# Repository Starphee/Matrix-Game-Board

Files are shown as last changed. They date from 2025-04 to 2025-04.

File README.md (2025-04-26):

# Matrix Game Board

*Interactive Multi-Matrix Tic Tac Toe Board*

---

## Project Overview

The **Matrix Game Board** is an original engineering project by Dorian Todd, designing and building an **interactive Tic Tac Toe** game using multiple **LED matrix displays** as both the **visual board** and the **input mechanism**.

Developed as a technical challenge, this project documents the entire process, from initial research and CAD design through manufacturing, complex wiring, assembly, testing, and iteration. It highlights the innovative approach of using the LED matrices themselves as pressure-sensitive buttons via underlying mechanical switches, all within a compact and portable form factor.

This repository contains the technical documentation, design files, firmware, and other resources related to the project.

> [!NOTE]
> This documentation serves to demonstrate the project's creation process and does not intend to be a step-by-step instruction manual for replication. 



## Key Features

*   **Interactive LED Display:** Utilizes nine 8x8 LED matrix modules (HT16K33) to display the Tic Tac Toe game state.
*   **Integrated Input:** Each matrix display doubles as a pressure-sensitive button via a low-profile mechanical keyboard switch mounted underneath.
*   **Tactile Feedback:** Mechanical switches provide satisfying tactile response for gameplay interaction.
*   **Compact Design:** Designed to fit within a 6.5-inch cubed area, adhering to competition constraints.
*   **Custom Enclosure:** Features a 3D-printed base with integrated component mounts and a laser-cut top panel.
*   **Advanced Electronics:** Incorporates an Adafruit Feather ESP32 V2 microcontroller, I2C multiplexing for displays, and analog multiplexing for switch inputs to manage numerous components efficiently.
*   **Audio Feedback:** Includes a Piezo Buzzer with volume control for game sounds.
*   **Battery Powered:** Designed with support for a Lithium Polymer battery for portability.
*   **Iterative Design Process:** Documentation showcases the challenges faced during prototyping, wiring, and assembly, and the design improvements made to overcome them.

## Technical Details

The project is built upon the following core components:

*   **Microcontroller:** Adafruit ESP32 Feather V2
*   **Display:** 9x Ada8x8 LED Matrix Modules (HT16K33)
*   **Display Multiplexer:** TCA9548A I2C Multiplexer (Manages the I2C addresses of the nine matrix displays)
*   **Input Switches:** 9x Kailh Low-Profile Mechanical Keyboard Switches
*   **Input Multiplexer:** CD74HC4067 16-Channel Analog Multiplexer (Condenses the 9 switch inputs down to 4 microcontroller pins)
*   **Audio:** 1x Piezo Buzzer, 1x Volume Potentiometer
*   **Power:** 1x Power Switch, 1x Power LED, 1x Lithium Polymer 1000mAh 3.7v battery (charging via ESP32's USB-C port)
*   **Casing:** 3D-printed PLA base, Laser-cut wood top panel / side panels

A complete Bill of Materials (BoM) can be found [here](#bill-of-materials) or in the technical documentation file.

## Project Files

This repository includes (or will include) the following files:

*   `Technical Documentation.pdf`: The source document detailing the project process.
*   `/CAD/`: Fusion360 files and exported formats (STL, STEP) for the 3D-printed base and laser-cut panels.
*   `/Laser_Cut_Files/`: Files (DXF or similar) used for laser cutting the panel parts.
*   `/Firmware/`: Arduino code for the ESP32 Feather, including game logic, display control, and input handling.
*   `/Wiring_Diagram/`: Image of the project's wiring diagram.
*   `/Bill_of_Materials/`: A more detailed list of components.
*   `/Images/`: Photos and renders from the documentation showcasing the build process and final design.

## Getting Started (Exploring the Project)

While this is not an instruction manual to build your own, you can explore the project by:

*   **Cloning** this repository.
*   **Reviewing** the `Technical Documentation.pdf` to understand the design process, challenges, and solutions.
*   **Examining** the CAD files to see the mechanical design and component layout.
*   **Reviewing** the wiring diagram to understand the electronic connections.
*   **Exploring** the firmware code to see how the game logic, displays, and inputs are handled.

## Credits

*   **Design and Programming:** [Dorian Todd](http://www.doriantodd.com)
*   **Technical Documentation:** Dorian Todd
*   **Image Sources (Acknowledged in Doc):** Adafruit Industries et al., Hackaday et al., Altium et al., Gaqqee Gem DIY et al., Sac Valley Manufacturing et al.
*   **Inspiration:** Adam Savage's "One Day Builds" methodology.

## License

This project is open-source. License WIP...

---

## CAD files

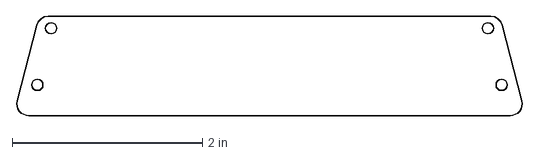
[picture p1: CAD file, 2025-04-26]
Laser Cut Files/newback.dxf
5.32 x 1.04 in

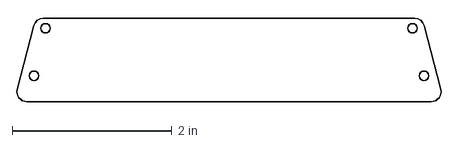
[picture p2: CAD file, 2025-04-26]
Laser Cut Files/newleft.dxf
5.32 x 1.04 in

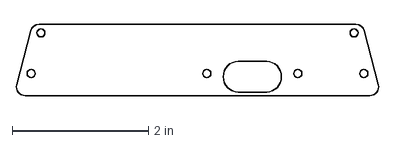
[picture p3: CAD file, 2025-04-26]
Laser Cut Files/newright.dxf
5.32 x 1.04 in

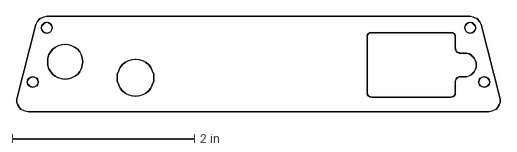
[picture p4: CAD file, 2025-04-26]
Laser Cut Files/newfront.dxf
5.32 x 1.04 in

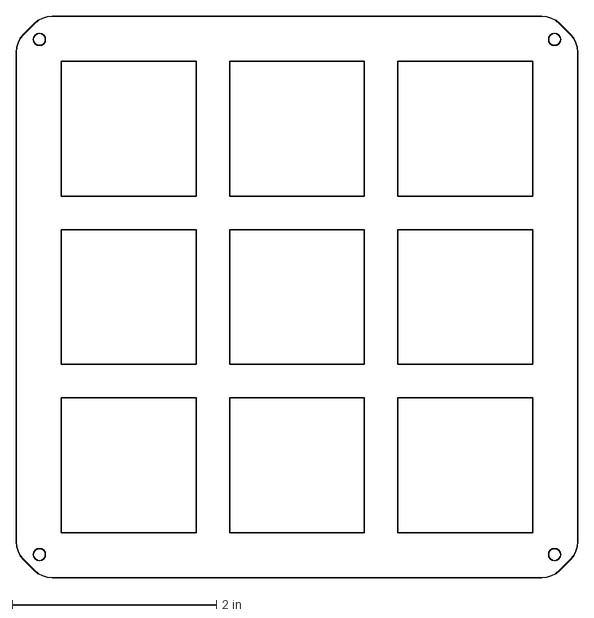
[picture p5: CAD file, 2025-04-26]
Laser Cut Files/topplate-newtolerence.dxf
5.50 x 5.50 in

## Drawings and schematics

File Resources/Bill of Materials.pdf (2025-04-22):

Item Name | Item Description | # Needed | # of packs | Cost per | Total Cost | Link

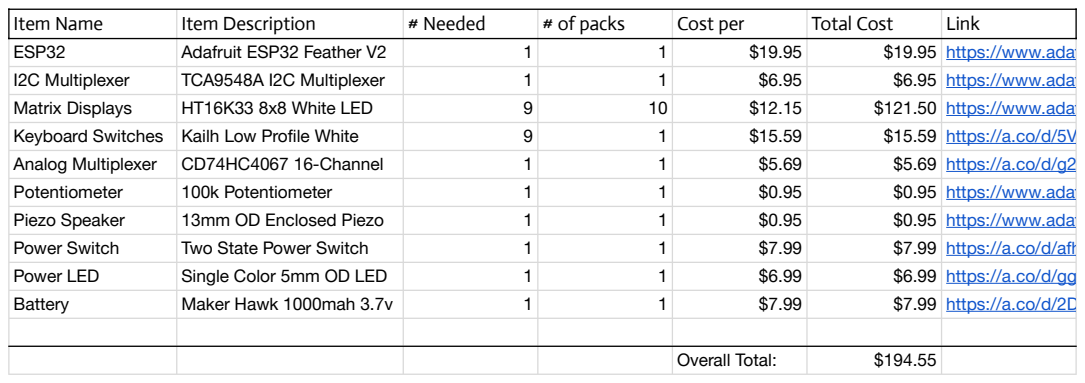
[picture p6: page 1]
ESP32; Adafruit ESP32 Feather V2; $19.95 https://www.adafruit.com/product/5400; I2C Multiplexer; TCA9548A I2C Multiplexer; $6.95 https://www.adafruit.com/product/2717; Matrix Displays; HT16K33 8x8 White LED; $121.50 https://www.adafruit.com/product/1080; Keyboard Switches Kailh Low Profile White; $15.59 https://a.co/d/5VzpAsS; Analog Multiplexer; CD74HC4067 16-Channel; $5.69 https://a.co/d/g2hOWRc; Potentiometer; 100k Potentiometer; $0.95 https://www.adafruit.com/product/1831; Piezo Speaker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

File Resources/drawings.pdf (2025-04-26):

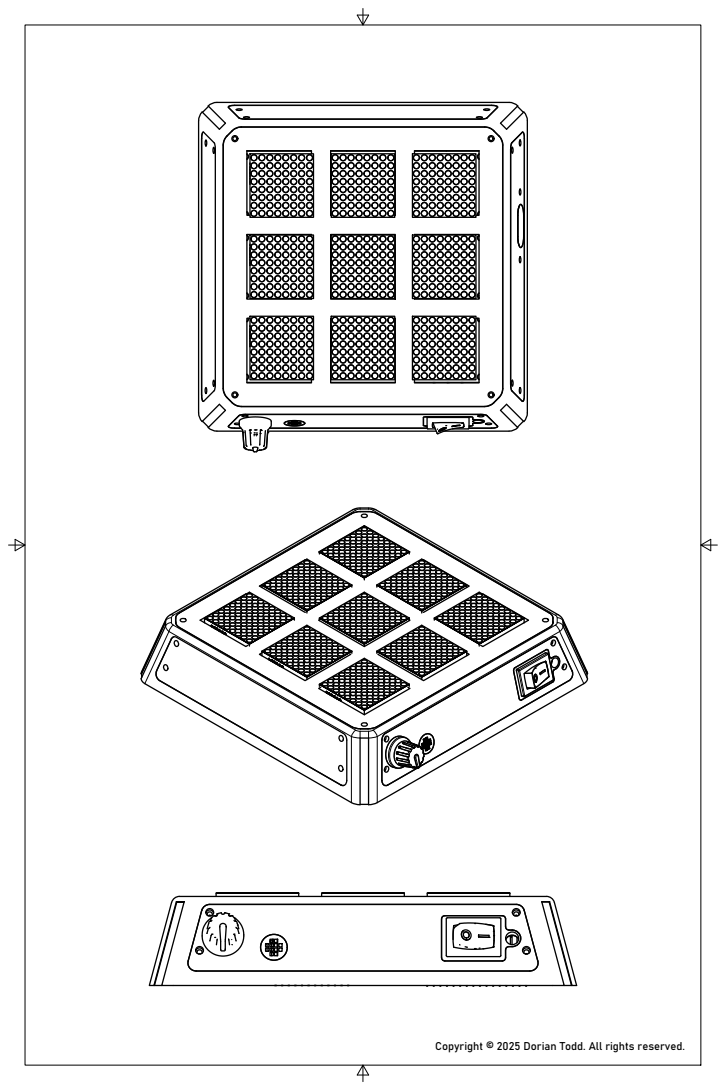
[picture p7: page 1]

Copyright © 2025 Dorian Todd. All rights reserved.

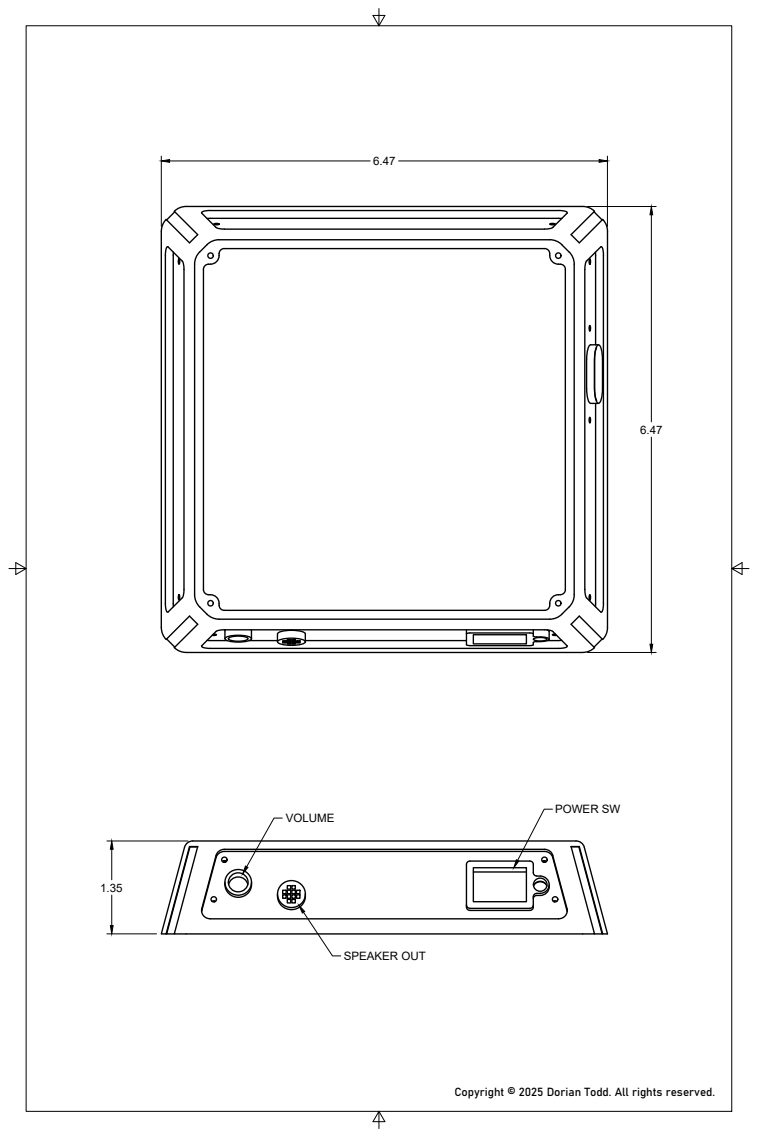
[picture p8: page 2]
SPEAKER OUT; POWER SW

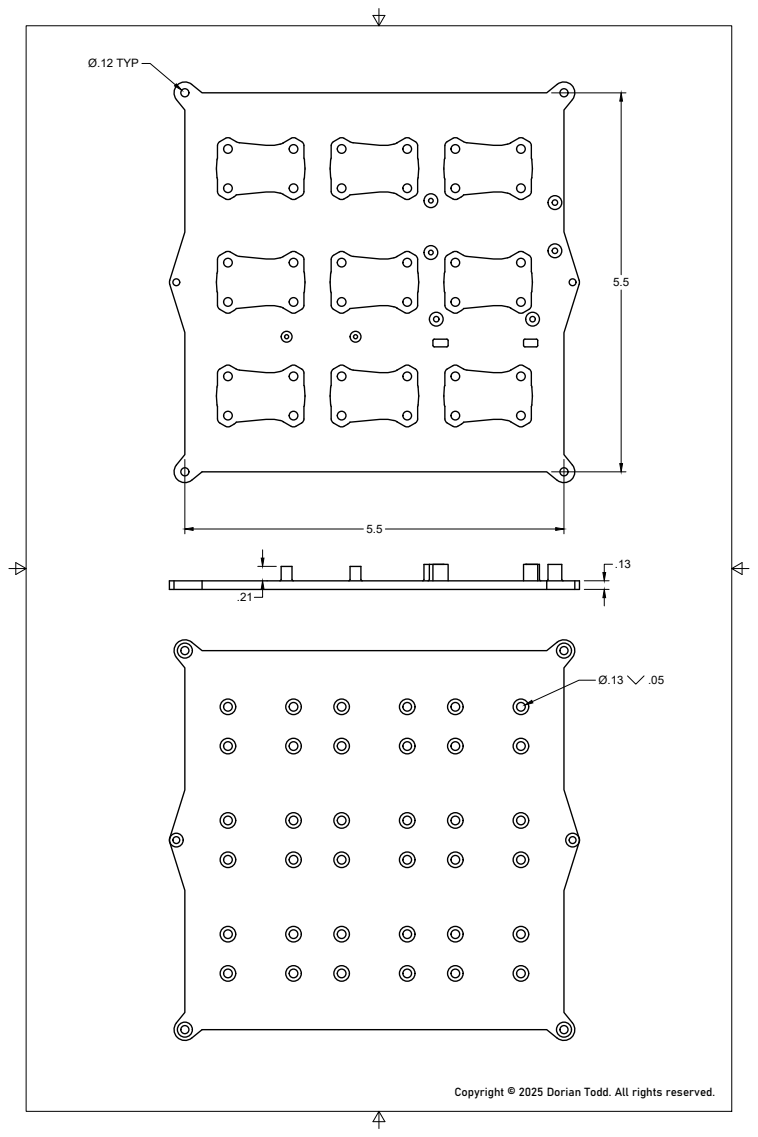
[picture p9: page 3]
Ø.12 TYP

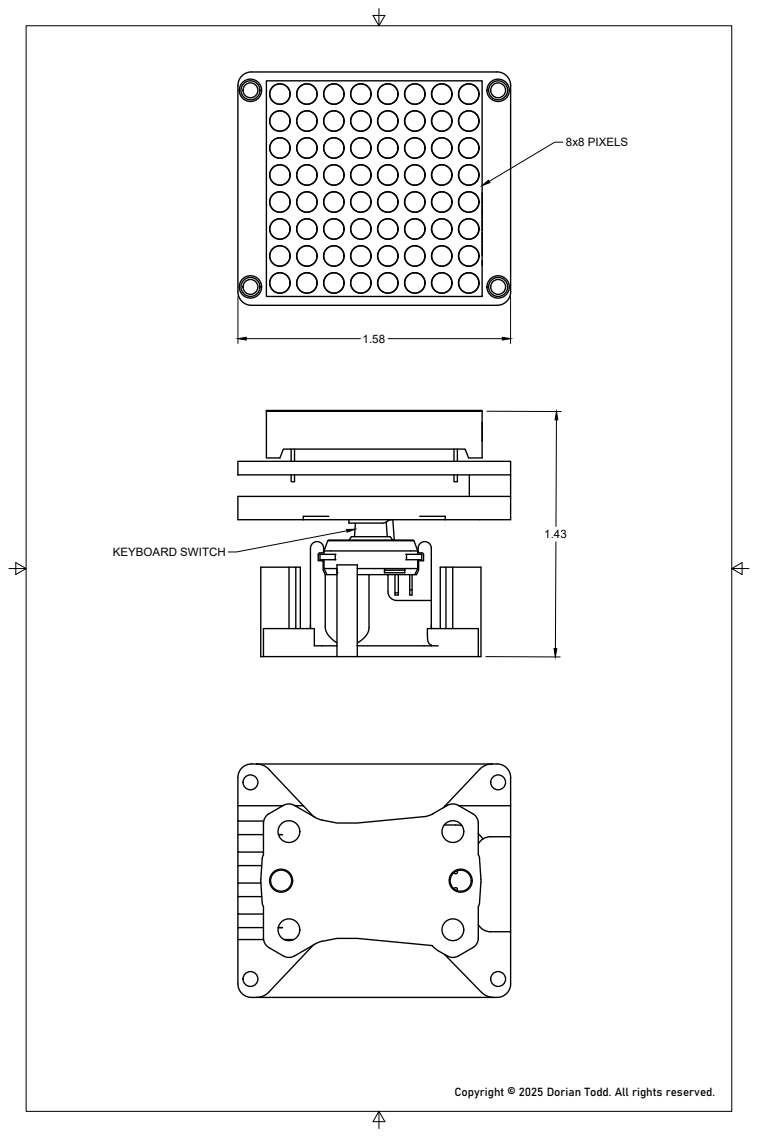
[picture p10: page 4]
8x8 PIXELS; KEYBOARD SWITCH

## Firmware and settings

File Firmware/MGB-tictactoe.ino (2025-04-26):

#include <Wire.h>
#include <Adafruit_GFX.h>
#include <Adafruit_LEDBackpack.h>

// --- Hardware Configuration ---
#define TCAADDR 0x70  // TCA9548A I2C Multiplexer address
const uint8_t MATRIX_ADDRESSES[3] = {0x71, 0x72, 0x74}; // Addresses on each TCA channel
const int MUX_S0 = 15, MUX_S1 = 14, MUX_S2 = 0, MUX_S3 = 8, MUX_SIG = 7; // Button MUX pins
const int PIEZO_PIN = A2; // Piezo pin

// --- Game Constants ---
const int BOARD_SIZE = 9;
const int EMPTY = 0;
const int PLAYER_X = 1;
const int PLAYER_O = 2;
const int DRAW = 3;

// --- Sound Frequencies & Durations (Hz, ms) ---
// Startup
const int STARTUP_FREQ1 = 523;  // C5
const int STARTUP_FREQ2 = 659;  // E5
const int STARTUP_FREQ3 = 784;  // G5
const int STARTUP_FREQ4 = 1046; // C6
const int STARTUP_DUR1 = 100;
const int STARTUP_DUR2 = 150;
// Game Start (per game)
const int GAME_START_FREQ1 = 1046; // C6
const int GAME_START_FREQ2 = 1318; // E6
const int GAME_START_DUR = 80;
// UI/Move Sounds
const int BUTTON_PRESS_FREQ = 2000;
const int BUTTON_PRESS_DUR = 20;
const int INVALID_MOVE_FREQ = 200;
const int INVALID_MOVE_DUR = 100;
const int PLAYER_X_MOVE_FREQ = 880; // A5
const int PLAYER_X_MOVE_DUR = 50;
const int PLAYER_O_MOVE_FREQ = 784; // G5
const int PLAYER_O_MOVE_DUR = 50;
// Win Sound (Fanfare)
const int WIN_NOTE_C5 = 523;
const int WIN_NOTE_G5 = 784;
const int WIN_NOTE_C6 = 1046;
const int WIN_NOTE_E6 = 1318;
const int WIN_NOTE_G6 = 1568;
const int WIN_DUR_SHORT = 120;
const int WIN_DUR_LONG = 250;
const int WIN_PAUSE = 30;
// Draw Sound
const int DRAW_FREQ = 440;        // A4
const int DRAW_DURATION = 200;

// --- Timings ---
const unsigned long RESET_DELAY = 3000; // 3 seconds delay before reset
const int ANIMATION_DELAY = 60;         // Delay between animation frames (ms)
const int WIN_FLASH_DELAY = 200;       // Delay for flashing winning line
const int SNAKE_PIXEL_DELAY = 10;      // Delay for startup snake (ms per pixel)
const int PULSE_DELAY = 150;          // Delay for win animation pulsing
const int WIPE_DELAY = 40;            // Delay for draw animation wipe (ms per row)


// --- Global Variables ---
Adafruit_8x8matrix matrices[BOARD_SIZE];
bool matrixInitialized[BOARD_SIZE] = {false};
bool prevButtonStates[BOARD_SIZE] = {false};
int board[BOARD_SIZE];
int currentPlayer;
bool gameOver;
int winner;
int movesMade;
int winningLine[3] = {-1,-1,-1};
unsigned long gameOverTimestamp;

// --- Function Prototypes ---
void tcaselect(uint8_t channel);
void initMatrices();
void resetGame();
void drawBoard();
void clearCell(uint8_t matrixIndex);
void drawX(uint8_t matrixIndex, bool animate);
void drawO(uint8_t matrixIndex, bool animate);
void updateCellDisplay(int index, bool animate);
void checkButtons();
bool readButton(int channel);
void makeMove(int index);
bool checkForWin();
bool checkForDraw();
void playStartupJingle();      // New
void playStartupAnimation();   // New
void playButtonPressSound();
void playInvalidMoveSound();
void playGameStartSound();
void playPlayerXMoveSound();
void playPlayerOMoveSound();
void playWinSound();           // Modified
void playDrawSound();
void animateWin();             // Modified
void highlightWinningLine(bool turnOn, int brightness); // Added brightness param
void animateDraw();            // Modified
void printBoardState();
void printPinInfo();


// =========================================================================
// SETUP FUNCTION
// =========================================================================
void setup() {
  Serial.begin(115200);
  while (!Serial) { delay(10); }

  Serial.println("\n--- Tic Tac Toe Game Initializing ---");

  // --- Hardware Setup ---
  Serial.println("Setting up hardware pins...");
  pinMode(MUX_S0, OUTPUT); pinMode(MUX_S1, OUTPUT); pinMode(MUX_S2, OUTPUT); pinMode(MUX_S3, OUTPUT);
  pinMode(MUX_SIG, INPUT_PULLUP);
  pinMode(PIEZO_PIN, OUTPUT); digitalWrite(PIEZO_PIN, LOW);
  printPinInfo();

  Serial.println("Initializing I2C and LED Matrices...");
  Wire.begin(); Wire.setClock(400000);
  initMatrices();

  // --- One-Time Startup Sequence ---
  playStartupJingle();
  playStartupAnimation();

  // --- Initialize First Game ---
  Serial.println("Setting up First Game...");
  resetGame(); // Initialize game variables, clear board, play game start sound

  Serial.println("\n--- Game Ready! Player X's Turn ---");
  printBoardState();
}

// =========================================================================
// MAIN LOOP FUNCTION
// =========================================================================
void loop() {
  if (!gameOver) {
    checkButtons(); // Poll buttons if game is active
  } else {
    // Check if reset delay has passed
    if (millis() - gameOverTimestamp >= RESET_DELAY) {
      Serial.println("\n--- Resetting Game ---");
      resetGame(); // Reset state, clear board, play game start sound
      Serial.println("--- Game Ready! Player X's Turn ---");
      printBoardState();
    }
  }
  delay(10); // Small delay to prevent excessive polling
}

// =========================================================================
// GAME LOGIC FUNCTIONS
// =========================================================================

void resetGame() {
  Serial.println("Resetting game variables and board.");
  // Reset game state variables
  for (int i = 0; i < BOARD_SIZE; i++) {
    board[i] = EMPTY;
    prevButtonStates[i] = false; // Reset button states for next game
  }
  currentPlayer = PLAYER_X; // X always starts
  gameOver = false;
  winner = EMPTY;
  movesMade = 0;
  winningLine[0] = winningLine[1] = winningLine[2] = -1; // Clear winning line info
  gameOverTimestamp = 0; // Reset timer

  drawBoard(); // Clear all matrix displays visually
  playGameStartSound(); // Sound for the start of *this* game session

  Serial.println("Board cleared. Player X starts.");
}

void makeMove(int index) {
  // Check if the move is valid
  if (board[index] == EMPTY && !gameOver) {
    // Play move sound first for responsiveness
    if (currentPlayer == PLAYER_X) {
      playPlayerXMoveSound();
    } else {
      playPlayerOMoveSound();
    }

    Serial.print("Player "); Serial.print(currentPlayer == PLAYER_X ? "X" : "O");
    Serial.print(" places mark at cell "); Serial.println(index + 1);

    // Update game state
    board[index] = currentPlayer;
    movesMade++;

    // Update display
    updateCellDisplay(index, true); // Draw X or O with animation
    printBoardState(); // Log board state

    // Check for game end conditions
    if (checkForWin()) {
        gameOver = true;
        winner = currentPlayer;
        gameOverTimestamp = millis(); // Start reset timer
        Serial.print("!!! Player "); Serial.print(currentPlayer == PLAYER_X ? "X" : "O"); Serial.println(" WINS !!!");
        animateWin(); // Play win animation (includes sound)
    } else if (checkForDraw()) {
        gameOver = true;
        winner = DRAW;
        gameOverTimestamp = millis(); // Start reset timer
        Serial.println("!!! GAME DRAW !!!");
        animateDraw(); // Play draw animation (includes sound)
    } else {
        // If game continues, switch player
        currentPlayer = (currentPlayer == PLAYER_X) ? PLAYER_O : PLAYER_X;
        Serial.print("Turn: Player "); Serial.println(currentPlayer == PLAYER_X ? "X" : "O");
    }
  } else { // Handle invalid move conditions
      if (board[index] != EMPTY) {
          Serial.print("Cell "); Serial.print(index+1); Serial.println(" is already occupied. Invalid move.");
      } else { // Game must be over
           Serial.println("Game is over. Cannot make move.");
      }
      playInvalidMoveSound(); // Play error sound for any invalid attempt
  }
}

bool checkForWin() {
  // Define all 8 winning combinations
  const int winPatterns[8][3] = {
    {0, 1, 2}, {3, 4, 5}, {6, 7, 8}, // Rows
    {0, 3, 6}, {1, 4, 7}, {2, 5, 8}, // Columns
    {0, 4, 8}, {2, 4, 6}             // Diagonals
  };

  // Check each pattern
  for (int i = 0; i < 8; i++) {
    int a = winPatterns[i][0];
    int b = winPatterns[i][1];
    int c = winPatterns[i][2];
    // Check if the cells are non-empty and match the current player
    if (board[a] != EMPTY && board[a] == board[b] && board[a] == board[c]) {
      // Store the winning line indices
      winningLine[0] = a;
      winningLine[1] = b;
      winningLine[2] = c;
      Serial.print("Win detected: Cells ");
      Serial.print(a+1); Serial.print("-"); Serial.print(b+1); Serial.print("-"); Serial.println(c+1);
      return true; // Win found
    }
  }
  return false; // No win found
}

bool checkForDraw() {
  // A draw occurs if all 9 moves have been made and no winner was declared *in the current check cycle*
  if (movesMade == BOARD_SIZE && winner == EMPTY) {
      Serial.println("Draw condition met (9 moves, no winner).");
      return true;
  }
  return false;
}

// =========================================================================
// BUTTON HANDLING FUNCTIONS
// =========================================================================

void checkButtons() {
  for (int i = 0; i < BOARD_SIZE; i++) {
    bool currentState = !readButton(i); // Read button state (inverted due to PULLUP)

    // Check for a state change (press or release)
    if (currentState != prevButtonStates[i]) {
      delay(20); // Basic debounce delay
      currentState = !readButton(i); // Read again after delay

      // Confirm state change after debounce
      if (currentState != prevButtonStates[i]) {
          prevButtonStates[i] = currentState; // Store the new stable state

          // Act only on button press (transition from HIGH to LOW)
          if (currentState) {
              playButtonPressSound(); // Play click sound for ANY confirmed press
              Serial.print("Button "); Serial.print(i+1); Serial.println(" pressed.");
              makeMove(i); // Attempt to make a move using the button index
          }
          // Optional: Could add logic here for button release if needed
      }
    }
  }
}

// Reads the state of a specific button channel via the MUX
bool readButton(int channel) {
  // Set MUX address lines based on the channel number
  digitalWrite(MUX_S0, channel & 0x01);        // LSB
  digitalWrite(MUX_S1, (channel >> 1) & 0x01);
  digitalWrite(MUX_S2, (channel >> 2) & 0x01);
  digitalWrite(MUX_S3, (channel >> 3) & 0x01); // MSB
  delayMicroseconds(5); // Allow MUX lines to settle
  // Read the signal pin (HIGH if not pressed, LOW if pressed due to PULLUP)
  return digitalRead(MUX_SIG);
}


// =========================================================================
// DISPLAY FUNCTIONS (LED Matrices)
// =========================================================================

// Selects the correct I2C bus on the TCA9548A
void tcaselect(uint8_t channel) {
  if (channel > 7) return; // Invalid channel
  Wire.beginTransmission(TCAADDR);
  Wire.write(1 << channel); // Send byte to select channel
  byte error = Wire.endTransmission();
  if (error != 0) {
    Serial.print("TCA select channel "); Serial.print(channel); Serial.print(" failed! Error code: "); Serial.println(error);
  }
  delayMicroseconds(100); // Short delay after switching channels might help stability
}

// Initialize all matrices
void initMatrices() {
  int initializedCount = 0;
  Serial.println("Initializing matrices...");
  for (uint8_t i = 0; i < BOARD_SIZE; i++) {
    uint8_t tcaChannel = i / 3; // Determine TCA channel (0, 1, or 2)
    uint8_t matrixAddr = MATRIX_ADDRESSES[i % 3]; // Determine address on that channel

    tcaselect(tcaChannel); // Select the correct I2C bus

    Serial.print("  Matrix "); Serial.print(i + 1);
    Serial.print(" (TCA Chan:"); Serial.print(tcaChannel);
    Serial.print(", Addr:0x"); Serial.print(matrixAddr, HEX); Serial.print(")... ");

    // Attempt to initialize the matrix
    if (matrices[i].begin(matrixAddr)) {
      matrices[i].setBrightness(7); // Set default brightness (0-15)
      matrices[i].setTextWrap(false); // Important for text rendering if used
      matrices[i].clear(); // Clear display buffer
      matrices[i].writeDisplay(); // Write buffer to matrix
      matrixInitialized[i] = true; // Mark as initialized
      Serial.println("OK");
      initializedCount++;
    } else {
      Serial.println("FAILED"); // Initialization failed
      matrixInitialized[i] = false;
    }
    delay(10); // Small delay between initializations
  }
  Serial.print("Matrix initialization complete. "); Serial.print(initializedCount); Serial.println("/9 matrices found.");
  if(initializedCount < BOARD_SIZE){
     Serial.println("!!! WARNING: Not all matrices initialized. Game may not display correctly. Check wiring and addresses.");
  }
}

// Draws the entire board based on the 'board' array (no animation)
void drawBoard() {
  // Serial.println("Drawing full board state to matrices."); // Less verbose
  for (int i = 0; i < BOARD_SIZE; i++) {
    updateCellDisplay(i, false); // Draw each cell without animation
  }
}

// Clears a single matrix display
void clearCell(uint8_t matrixIndex) {
   if (!matrixInitialized[matrixIndex]) return; // Skip if not initialized
   tcaselect(matrixIndex / 3); // Select correct I2C channel
   matrices[matrixIndex].clear();
   matrices[matrixIndex].writeDisplay();
}

// Draws an 'X' on the specified matrix with expanding animation
void drawX(uint8_t matrixIndex, bool animate) {
    if (!matrixInitialized[matrixIndex]) return; // Skip if not initialized
    tcaselect(matrixIndex / 3);
    Adafruit_8x8matrix &m = matrices[matrixIndex]; // Use a reference for cleaner code
    m.clear(); // Clear previous content

    if (animate) {
        // Expanding X from center, step-by-step
        // Step 1: Center pixels
        m.drawPixel(3, 3, LED_ON); m.drawPixel(4, 4, LED_ON);
        m.drawPixel(3, 4, LED_ON); m.drawPixel(4, 3, LED_ON);
        m.writeDisplay();
        delay(ANIMATION_DELAY);

        // Step 2: Expand one step
        m.drawPixel(2, 2, LED_ON); m.drawPixel(5, 5, LED_ON);
        m.drawPixel(2, 5, LED_ON); m.drawPixel(5, 2, LED_ON);
        m.writeDisplay();
        delay(ANIMATION_DELAY);

        // Step 3: Expand second step
        m.drawPixel(1, 1, LED_ON); m.drawPixel(6, 6, LED_ON);
        m.drawPixel(1, 6, LED_ON); m.drawPixel(6, 1, LED_ON);
        m.writeDisplay();
        delay(ANIMATION_DELAY);

        // Step 4: Corners (final)
        m.drawPixel(0, 0, LED_ON); m.drawPixel(7, 7, LED_ON);
        m.drawPixel(0, 7, LED_ON); m.drawPixel(7, 0, LED_ON);
        m.writeDisplay();
        // No delay after final step, move sound plays next

    } else {
        // Draw immediately without animation
        m.drawLine(0, 0, 7, 7, LED_ON);
        m.drawLine(0, 7, 7, 0, LED_ON);
        m.writeDisplay();
    }
}


// Draws an 'O' on the specified matrix with expanding animation
void drawO(uint8_t matrixIndex, bool animate) {
  if (!matrixInitialized[matrixIndex]) return; // Skip if not initialized
  tcaselect(matrixIndex / 3);
  Adafruit_8x8matrix &m = matrices[matrixIndex];
  m.clear(); // Clear previous content

  if (animate) {
    // Simple expanding circle animation
    m.drawCircle(3, 3, 1, LED_ON); // Small inner circle (center is between 3,3 and 4,4)
    m.writeDisplay();
    delay(ANIMATION_DELAY);
    m.drawCircle(3, 3, 2, LED_ON); // Middle circle
    m.writeDisplay();
    delay(ANIMATION_DELAY);
    m.drawCircle(3, 3, 3, LED_ON); // Outer circle (radius 3 fits well on 8x8)
    m.writeDisplay();
    // No delay after final step
  } else {
     // Draw full circle immediately
     m.drawCircle(3, 3, 3, LED_ON);
     m.writeDisplay();
  }
}

// Updates a single cell display based on the board state
void updateCellDisplay(int index, bool animate) {
  if (index < 0 || index >= BOARD_SIZE || !matrixInitialized[index]) return; // Validate index and initialization

  // Choose drawing function based on board state
  switch (board[index]) {
    case PLAYER_X:
      drawX(index, animate);
      break;
    case PLAYER_O:
      drawO(index, animate);
      break;
    case EMPTY:
    default:
      clearCell(index); // Clear the cell if empty
      break;
  }
}

// Animation for a win - includes sound now
void animateWin() {
    Serial.println("Playing Win Animation & Sound...");
    playWinSound(); // Play the fanfare first

    // Flash the winning line 5 times
    Serial.println("Flashing winning line...");
    for (int i = 0; i < 5; i++) {
        highlightWinningLine(true, 15);  // Highlight bright (max brightness)
        delay(WIN_FLASH_DELAY);
        highlightWinningLine(false, 0); // Turn off (brightness 0, effectively off)
        delay(WIN_FLASH_DELAY);
    }

    // Pulse the winning line 3 times
    Serial.println("Pulsing winning line...");
    for (int pulse = 0; pulse < 3; pulse++) {
         highlightWinningLine(true, 5);  // Set to Dim brightness
         delay(PULSE_DELAY);
         highlightWinningLine(true, 15); // Set to Bright brightness
         delay(PULSE_DELAY);
    }
    // Leave the winning line highlighted brightly
    highlightWinningLine(true, 15);
    Serial.println("Win animation complete.");
}

// Turns the LEDs of the winning line on or off, with specific brightness
void highlightWinningLine(bool turnOn, int brightness) {
    if (winningLine[0] == -1) return; // No winning line stored

    for(int i=0; i<3; i++){
        int cellIndex = winningLine[i];
        // Check if the cell index is valid and the matrix is initialized
        if(cellIndex >= 0 && cellIndex < BOARD_SIZE && matrixInitialized[cellIndex]){
            tcaselect(cellIndex / 3); // Select correct I2C channel
            matrices[cellIndex].setBrightness(brightness); // Set desired brightness

            if(turnOn) {
                 // Re-draw the X or O (without animation) to ensure it's visible at the new brightness
                 if(board[cellIndex] == PLAYER_X) drawX(cellIndex, false);
                 else if(board[cellIndex] == PLAYER_O) drawO(cellIndex, false);
                 // drawX/O calls writeDisplay implicitly
            } else {
                // Turn off for flashing effect
                matrices[cellIndex].clear();
                matrices[cellIndex].writeDisplay();
            }
        }
    }
    // Note: Brightness setting persists on the matrix until changed again
}

// Animation for a draw - includes sound now
void animateDraw() {
    Serial.println("Playing Draw Animation & Sound...");
    playDrawSound(); // Play draw sound first

    // Simple animation: Fill all screens briefly
    Serial.println("Filling screens for draw...");
    for (int i = 0; i < BOARD_SIZE; i++) {
        if (matrixInitialized[i]) {
            tcaselect(i / 3);
            matrices[i].fillScreen(LED_ON);
            matrices[i].writeDisplay();
        }
    }
    delay(300); // Show filled screens for a moment

    // Draw a checkerboard pattern as a draw indicator
    Serial.println("Displaying checkerboard pattern...");
    for (int i = 0; i < BOARD_SIZE; i++) {
        if (matrixInitialized[i]) {
            tcaselect(i / 3);
            matrices[i].clear();
            for(int y=0; y<8; y++) {
                for(int x=0; x<8; x++) {
                    // Alternate pattern based on matrix index for visual interest
                    if ((x+y) % 2 == (i % 2)) {
                       matrices[i].drawPixel(x, y, LED_ON);
                    }
                }
            }
            matrices[i].writeDisplay();
        }
    }
    delay(1000); // Show checkerboard pattern for a second

    // Wipe clear effect (downwards)
    Serial.println("Wiping draw animation...");
    for (int y = 0; y < 8; y++) { // Iterate through rows top to bottom
        for (int i = 0; i < BOARD_SIZE; i++) { // Modify all matrices for this row
             if (matrixInitialized[i]) {
                tcaselect(i / 3);
                // Draw a horizontal line of OFF pixels to clear the row
                matrices[i].drawFastHLine(0, y, 8, LED_OFF);
             }
        }
         // Update displays after modifying the row on all matrices simultaneously
         for (int i = 0; i < BOARD_SIZE; i++) {
             if (matrixInitialized[i]) {
                tcaselect(i / 3);
                matrices[i].writeDisplay();
             }
         }
        delay(WIPE_DELAY); // Delay between wiping rows
    }
    // All screens should be clear now, ready for reset delay
    Serial.println("Draw animation complete.");
}


// =========================================================================
// SOUND FUNCTIONS
// =========================================================================

void playStartupJingle() {
  Serial.println("Playing Startup Jingle...");
  tone(PIEZO_PIN, STARTUP_FREQ1, STARTUP_DUR1); delay(STARTUP_DUR1 + 20);
  tone(PIEZO_PIN, STARTUP_FREQ2, STARTUP_DUR1); delay(STARTUP_DUR1 + 20);
  tone(PIEZO_PIN, STARTUP_FREQ3, STARTUP_DUR1); delay(STARTUP_DUR1 + 20);
  tone(PIEZO_PIN, STARTUP_FREQ4, STARTUP_DUR2); delay(STARTUP_DUR2); // Wait for last note
  Serial.println("Startup Jingle Finished.");
}
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

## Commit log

2025-04-22 Added PDF file for bill of materials
    - added pdf version of the bill of materials for hardware electronics.
    - exported from google sheets (https://docs.google.com/spreadsheets/d/1HKscph1v5Xq0eHSIs5mIoXT-V_NWiScEPeThcPNUYu4/edit?usp=sharing)
2025-04-22 Rename Matrix Game Board Bill of Materials (Electronics).pdf to bill-of-materials.pdf
2025-04-26 Add main arduinocode program file for tic tac toe
    runs on the esp32 feather V2
2025-04-26 Added files to Laser Cut Files
    added early dxf files for laser cutting
    removed temp file.
    [newback.dxf, newfront.dxf, newleft.dxf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]
2025-04-26 Add wiring diagram pdf to resources
2025-04-26 Update README.md With CAD photo
